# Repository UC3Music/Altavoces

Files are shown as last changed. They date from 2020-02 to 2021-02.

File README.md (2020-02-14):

# Altavoces
Nuestros diseños de altavoces

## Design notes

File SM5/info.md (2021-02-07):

# SM5 (Studio Monitor 5")
Monitores de escritorio con cajas impresas en 3D.

## Configuración:
- Dos vías con bass reflex.
  - Cono de 5" Fane Studio 5 FR
  - tweeter de cúpula Beyma T2030.
- Caja de 10 litros con puerto afinado a 60Hz. Rango de frecuencias -3dB 62-20KHz.

- Amplificación activa no autoamplificada. Toda la amplificación y procesado en una caja a parte.
- Procesado: TRacks DSP 4x4 Mini
- Amplificación: TDA7498 160W x4
- Fuente de alimentación: Mean Well EPP-500-36V

## Conexiones

## Esquema

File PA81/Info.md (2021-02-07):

# Proyecto Altavoces UC3Music

- Sistema de sonido
- Alto rendimiento
- Multipropósito
- Compacto
- Portable
- Límite de presupuesto 900€

Utilizaremos una configuración de altavoz de 8 pulgadas con motor de compresión de 1 pulgada.
Sistema de amplificación activo no autoamplificado. (Filtros y eq. antes de la amplificación en vías separadas, pero amplificadores externos a la caja del altavoz.
Seguiremos esta guía: http://www.eighteensound.com/media/W1siZiIsIjIwMTgvMTAvMjMvMTFfMzVfNTZfOF8xOF9Tb3VuZF84XzJfV2F5c192MS5wZGYiXV0/18_Sound_8_2_Ways_v1.pdf

## Altavoces:

### Medios graves:
Marca: 18Sound
Modelo: 8MB500

### Agudos:
Marca: 18Sound
Modelo: ND1070

### Difusor:
Marca 18Sound
Modelo: XT120

Compraremos este kit, que se ahorran algunas pelas: https://www.lean-business.co.uk/eshop/8%C3%82%E2%80%9D-2-way-loudspeaker-system-kit-p-1312.html 2*206,94€+28,17€ gastos de envío= 442,05€

## Caja y materiales para su construcción: 52.69€

- Tablero: https://www.bricomart.es/tablero-contrachapado-de-chopo-215-x-60-x-1-8-cm.html 26€
- Pintura: https://www.thomann.de/es/warnex_strukturlack_1kg.htm 24,90€
- Conector: Neutrik NL4 MP https://www.thomann.de/es/neutrik_nl4mp_dtyp.htm 1,79€
- Cola para madera:
- Tornillos:
- Tintero

## Amplificación: Contamos con dos opciones disponibles.

### Amplificación 1: 298€ 
T.Amp TSA 4-300 https://www.thomann.de/es/the_tamp_tsa_4_300.htm
Mejor en peso y tamaño. 298€

### Amplificación 2: 328€
Behringer KM1700 179€
Behringer EPQ304 Europower 149€
Mejoramos en potencia pero incrementamos el peso.

# Subtotal: 822,74€

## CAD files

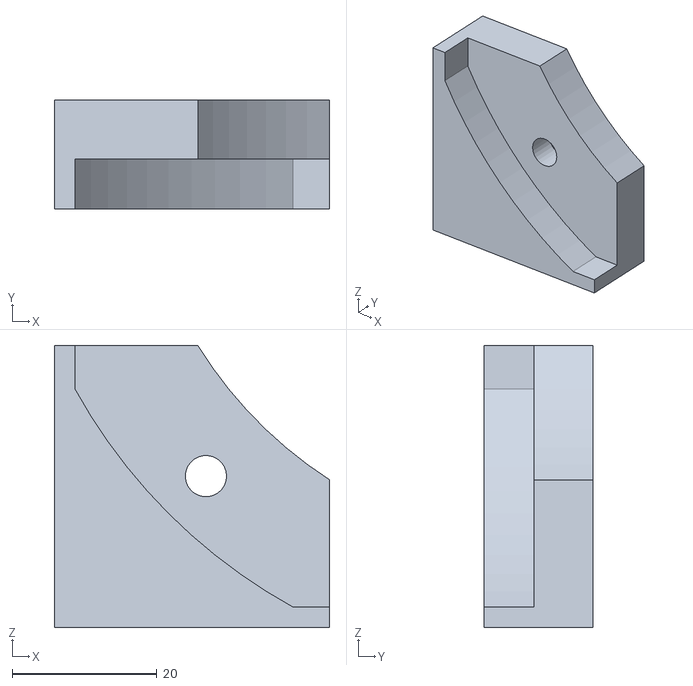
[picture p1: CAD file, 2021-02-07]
SM5/PruebaEsquina.stl
38.0 x 15.0 x 39.0

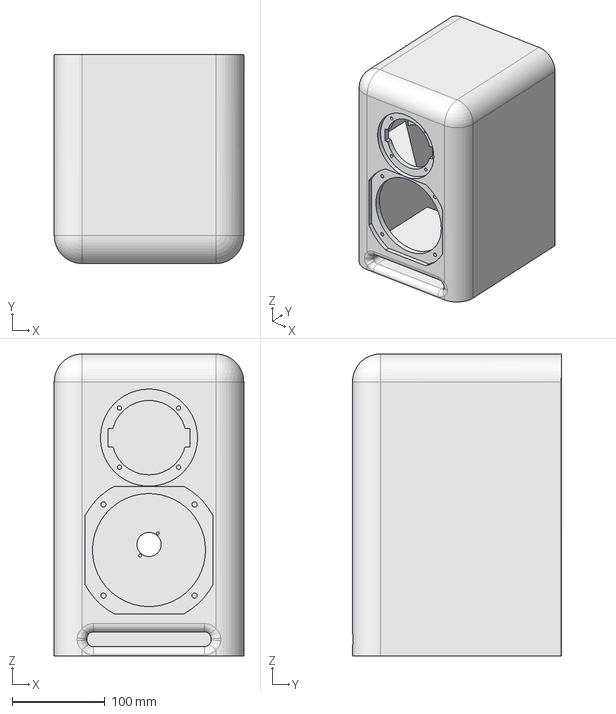
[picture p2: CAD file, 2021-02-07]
SM5/SM5.FCStd
204.0 x 225.0 x 325.0 mm

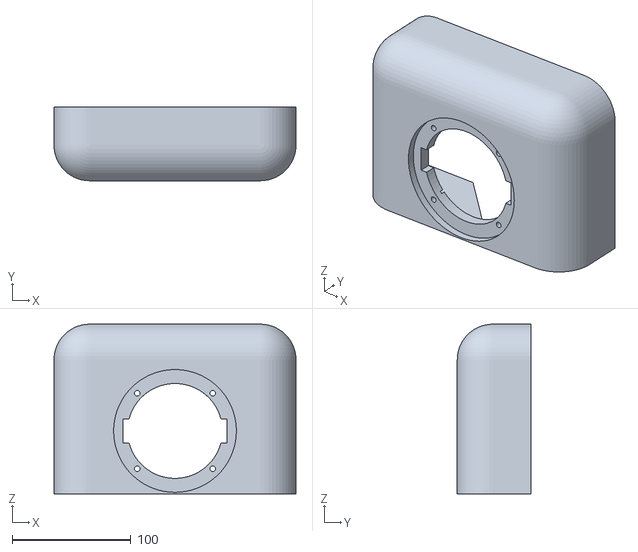
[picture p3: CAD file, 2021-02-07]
SM5/PruebaTw08.stl
204.0 x 62.0 x 143.0

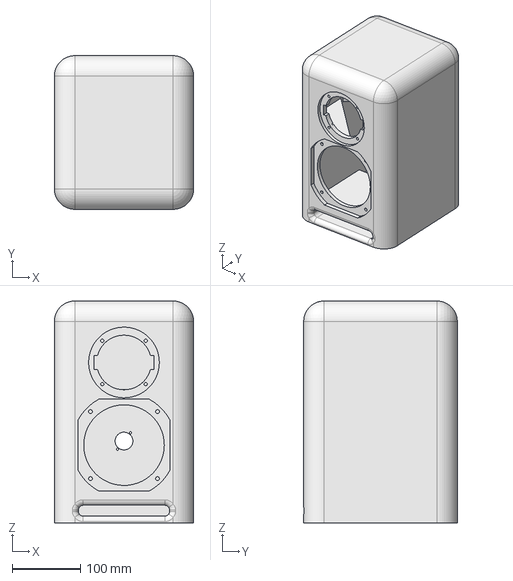
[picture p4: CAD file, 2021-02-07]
SM5/SM5-rev06.FCStd
204.0 x 225.0 x 325.0 mm

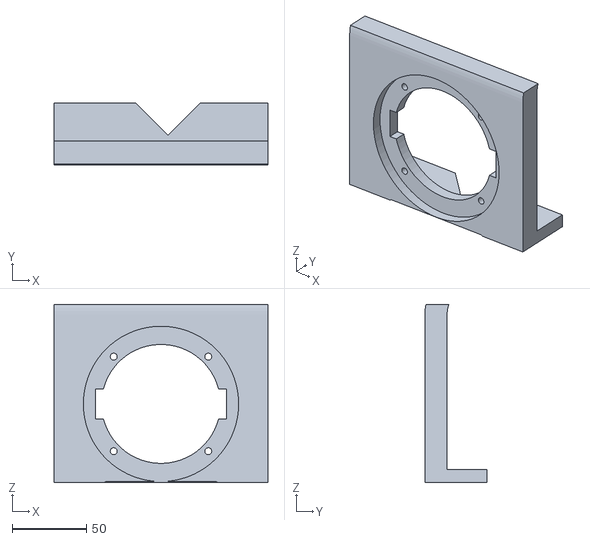
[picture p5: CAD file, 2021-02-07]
SM5/PruebaTweeter.stl
144.0 x 42.0 x 120.0

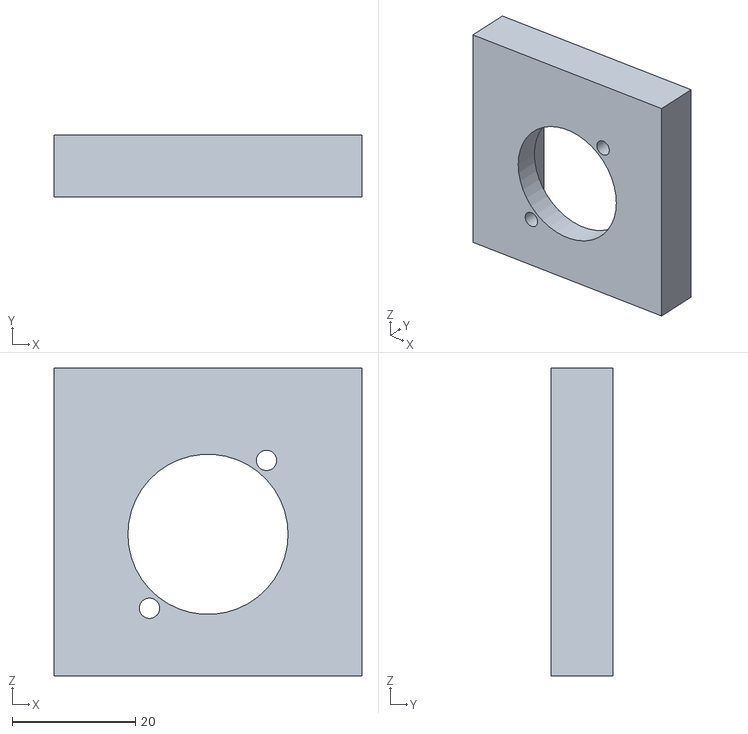
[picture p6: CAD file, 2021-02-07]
SM5/PruebaSpeakon.stl
50.0 x 10.0 x 50.0

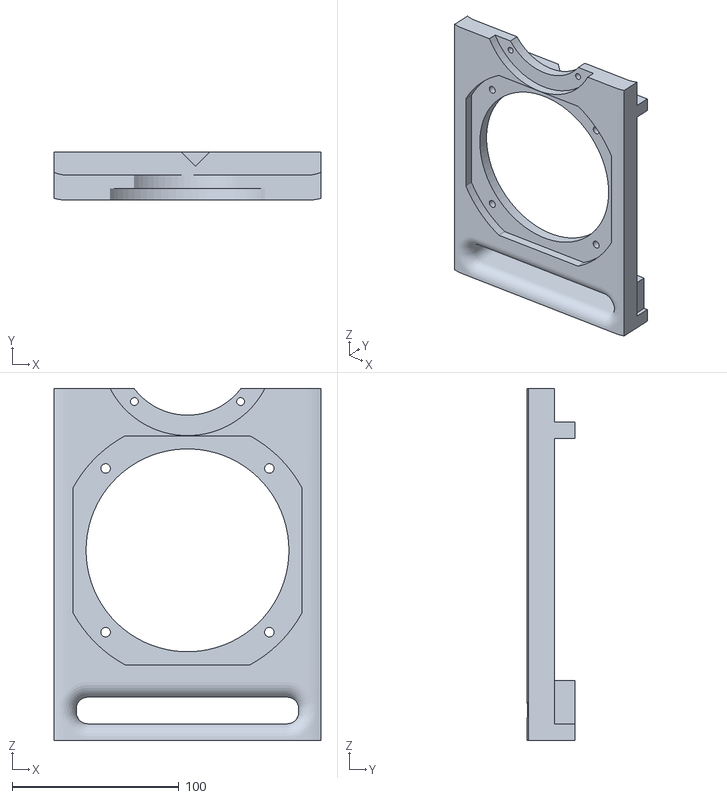
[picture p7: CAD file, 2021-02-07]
SM5/PruebaWoofer.stl
160.0 x 29.0 x 211.0

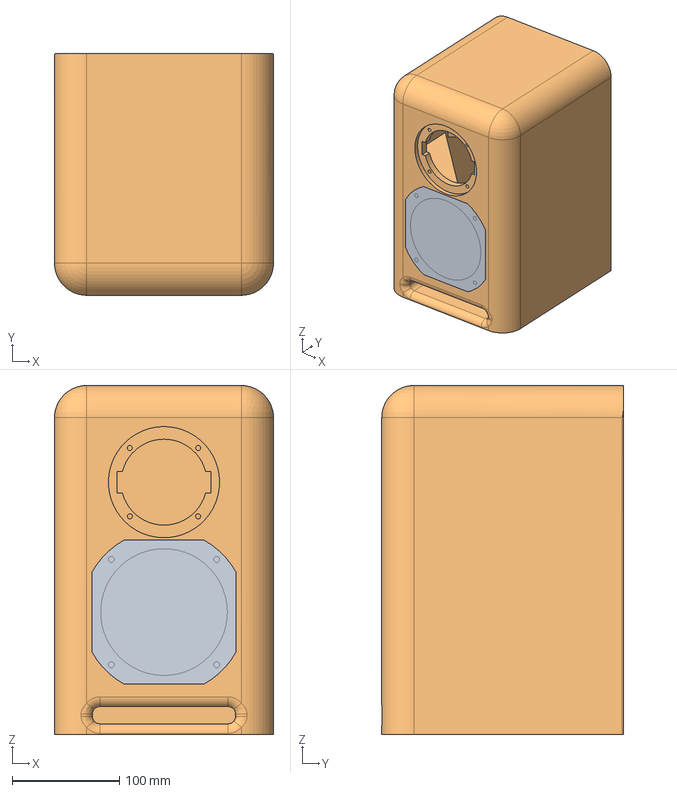
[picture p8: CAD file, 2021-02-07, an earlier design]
SM5/SM5-rev0.FCStd
204.0 x 225.0 x 325.0 mm
Woofer
Flanges

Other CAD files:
SM5/SM5-rev05.FCStd
SM5/SM5-rev1.FCStd
SM5/SM5.stl
SM5/SM5rev05.stl
SM5/SM5rev06.stl
SM5/SM5rev1.stl

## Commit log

2020-02-14 link de la guía
2020-02-14 Mejoras en el formato
2020-02-14 Mejoras en el formato 2
2021-02-07 diseños preliminares del SM5
    [PruebaEsquina.stl, PruebaSpeakon.stl, PruebaTw08.stl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]
